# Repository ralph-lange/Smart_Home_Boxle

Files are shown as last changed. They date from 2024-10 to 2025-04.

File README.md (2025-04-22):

# Smart Home Böxle

The Smart Home Böxle is a pretty little wooden box that combines a classic analogue ammeter with an e-Ink display to visualize home automation data. (‘Böxle’ is German, Swabian to be precise, and means ‘little box’.)

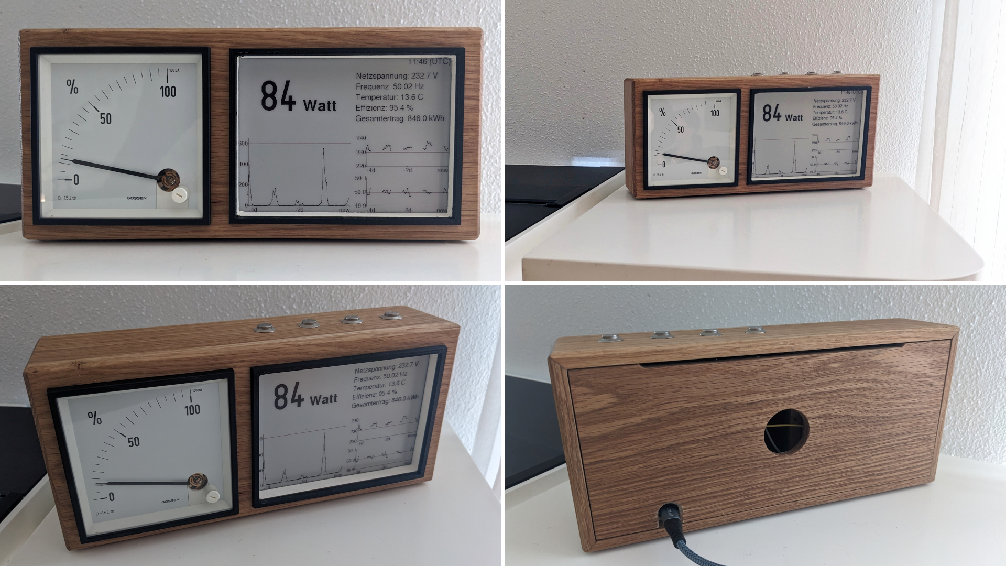
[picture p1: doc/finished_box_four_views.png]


## Parts list

- 8mm solid wood (here oak was used)
- ESP32 Dev Kit C
- 5.83" E-Paper Display Module by Waveshare (648×480&hairsp;px, black/red/white)
- Analog ammeter or voltmeter with size 96x96&hairsp;mm (here a 100&hairsp;µA ammeter by [Gossen](https://g-mw.de/) was used)
- USB-C female socket
- Micro-USB cable
- Pushbutton switches (4 pieces)
- Acrylic glass panel (here a black panel was used)
- White acrylic paint

... and some DuPont cables, PCB spacers, pin strip, heat shrink tube, and similar typical electronic components.

For the black frame around the cutout of the e-paper display, a standard 3D printer was used.

## Build instructions

The box consists of a rectangular body and a front panel. At the back, a removable cover is inserted into the body.

It is best to first cut the cutouts for the ammeter and the e-paper display in the front panel on a router table. Only then saw the front panel to size, with one or two millimeters tolerance on all four sides.

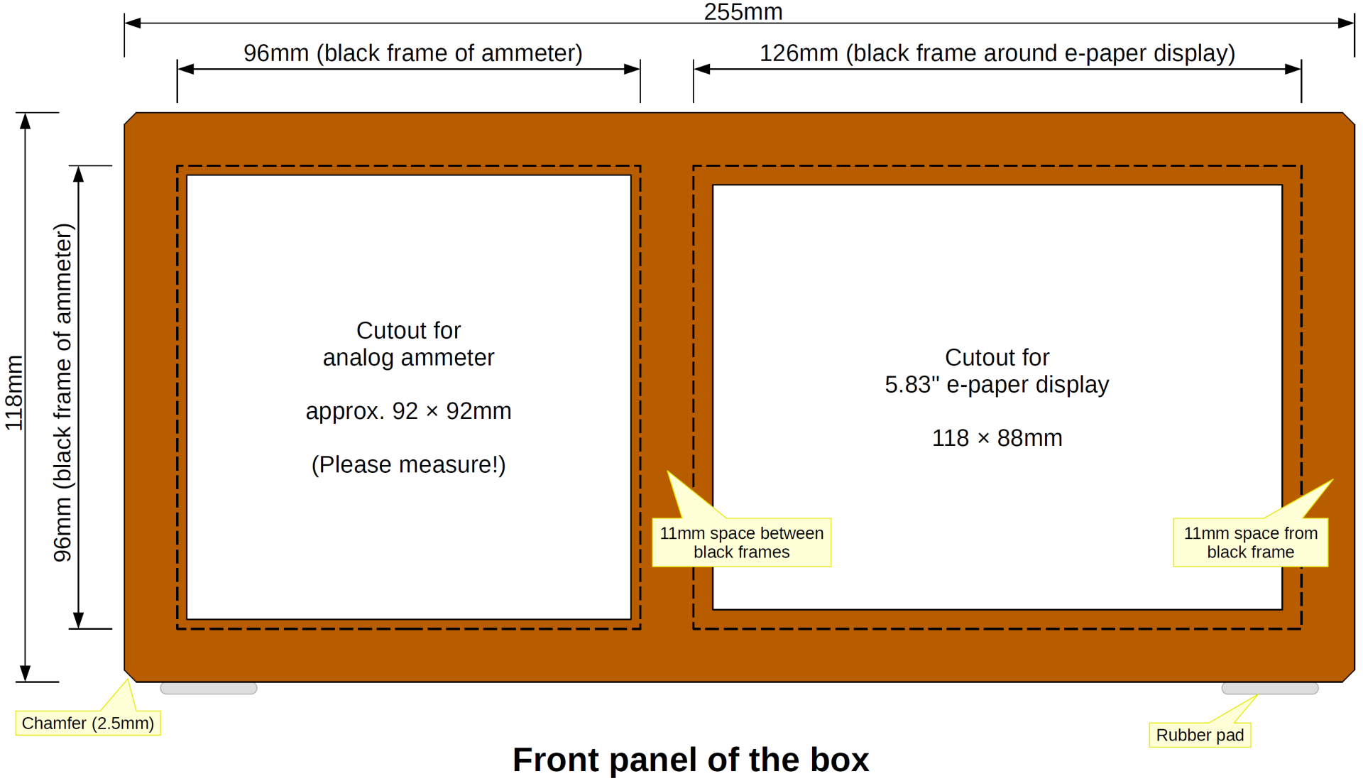
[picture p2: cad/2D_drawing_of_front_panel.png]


The body is built from four wood strips of the same width with 45° miters. The width of the wood strips is determined primarily by the depth of the ammeter. The lengths of the wood strips are 255mm and 118mm, respectively.

But before gluing the wood strips, drill four holes for the pushbutton switches into the top wood strip. Furthermore, remove a small strip on the upper inside front for the e-paper display since the display's top border is wider than the other borders.

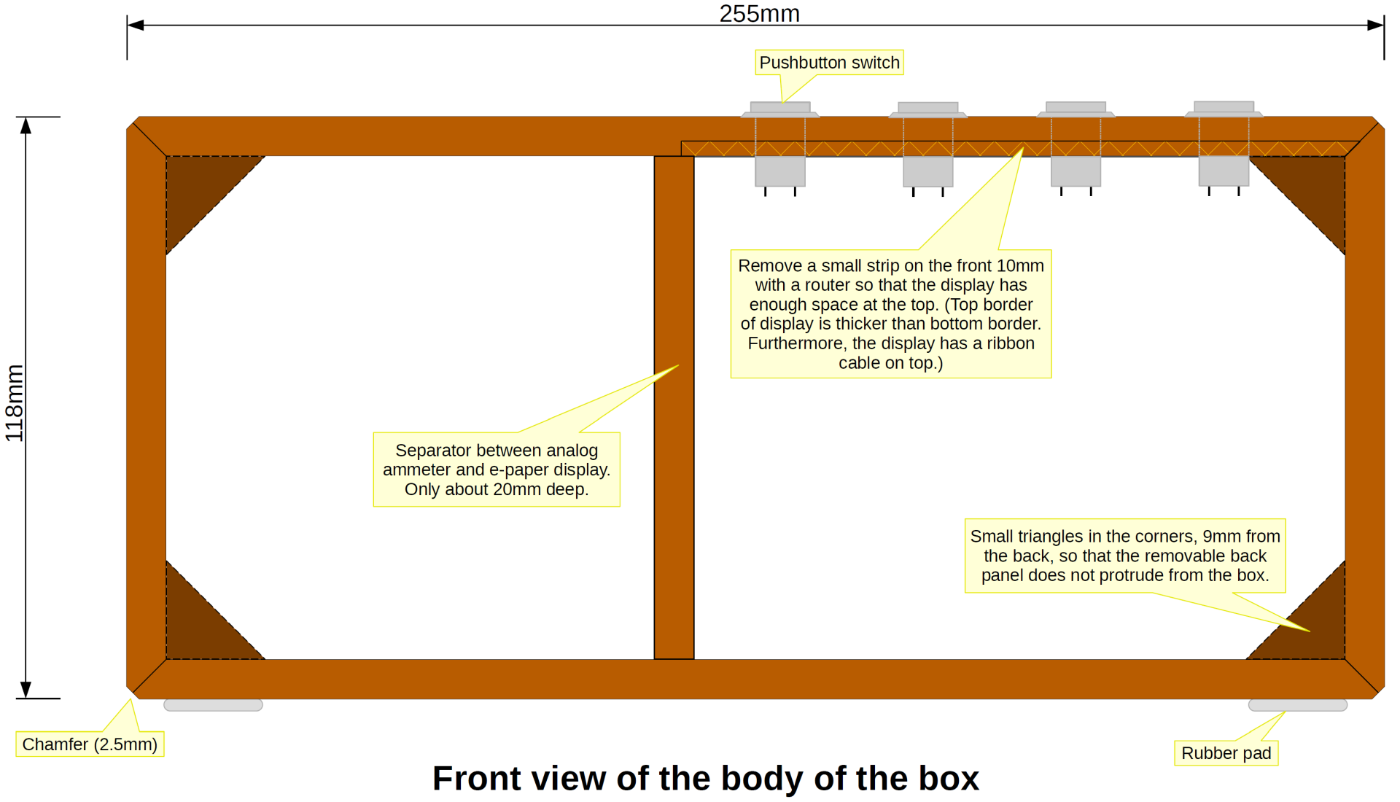
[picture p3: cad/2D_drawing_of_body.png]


Glue small triangles 9mm from the back into the corners of the body. Furthermore, glue a vertical separator between the space for the ammeter and the space for the e-paper display.

Glue the front panel on the body, remove the protruding wood of the front panel using a flush cutter on a router table. Cut a small chamfer all around the box.

Paint the inner sides of the cutout for the e-paper display with a white acrylic paint.

The e-paper display is delivered with a small ribbon cable and a driver board. Cut a (black) acrylic glass panel that is slightly larger than the display but small enough to fit in the right half of the box. Mount the driver board on the acrylic glass panel, guide the ribbon cable over the edge and attach the display to the other side of the acrylic glass panel with adhesive pads. Slide the acrylic glass panel with the display into the box from the back and place it vertically behind the cutout.

In the photo below, the acrylic glass panel is fixed on the left and right by two other acrylic glass panels which were glued with double-sided adhesive tape.

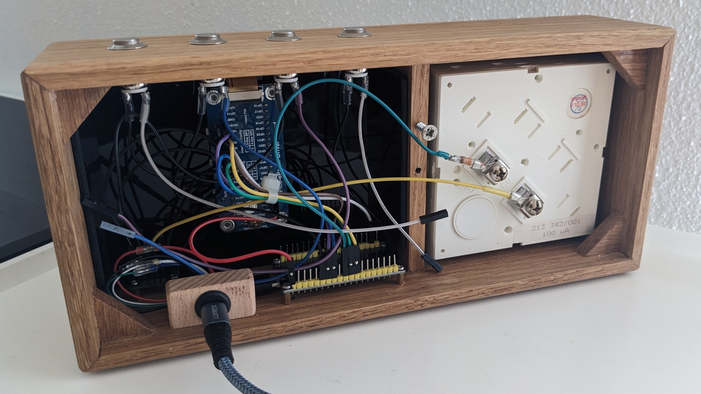
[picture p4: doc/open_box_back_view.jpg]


The wiring of the driver board for SPI is shown below on the left.

After inserting and tightening the four pushbutton switches, mount the ESP32 reversed at the bottom of the frame using PCB spacers. I screwed the spacers through the wood from below. I also drilled a hole from the bottom side to the boot button so that it can be pushed with a thin pen or screwdriver for flashing the ESP32. (Alternatively, you may ground GPIO 0 with a DuPont cable for entering the flashing mode.)

In addition to the ESP32, I mounted a small circuit board with a pin strip for grounding the pushbutton switches, the e-paper display, and the ammeter to the GND pin of the ESP32. The middle image below shows this pin strip.

For power supply and flashing, I cut off a four-wire micro-USB cable and soldered it to a four-contact USB-C socket (see photo below right). The socket is attached using a small wooden block.

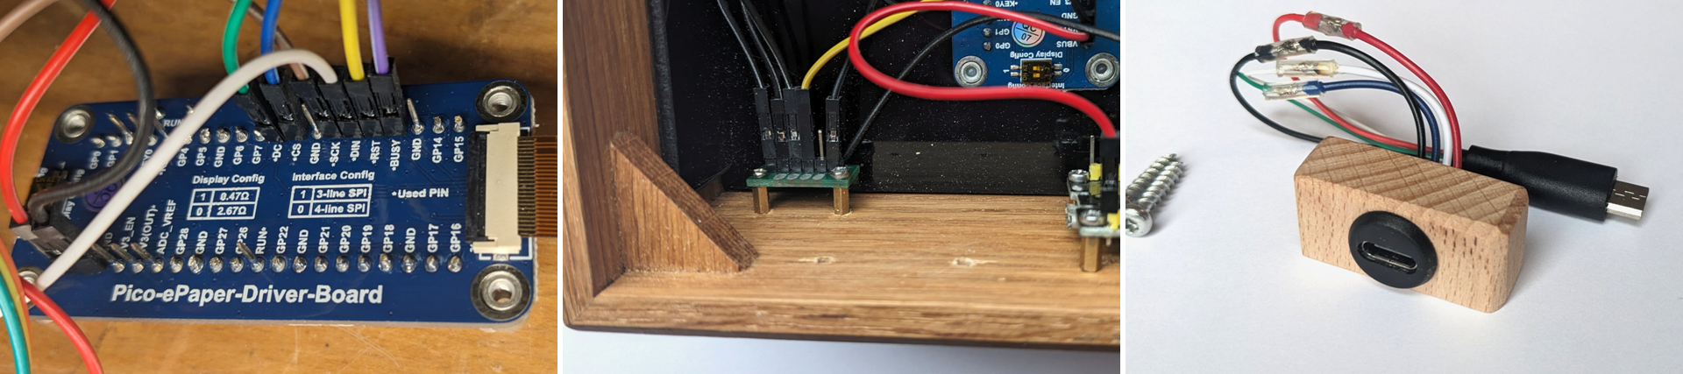
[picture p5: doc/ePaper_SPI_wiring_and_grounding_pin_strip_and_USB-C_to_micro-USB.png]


Mount/glue a small black frame around the cutout of the e-paper display. An STL file for 3D printing such a frame can is stored at [cad/black_frame_for_e-paper_display.stl](cad/black_frame_for_e-paper_display.stl).

Next, insert the ammeter in the box. I fixed it with some foam stuffed around the ammeter.

The last step is the back cover, which is placed in the body. Drill a finger-sized hole in the center so that it can be easily taken out. I used a hand-held router to additionally drill two holes for the contacts of the ammeter, which protrude a little further. Furthermore, I glued in a small magnet to hold the cover magnetically at a screw in the vertical wood strip between the ammeter and the e-paper display. To avoid any interference, ensure that the screw and the magnet are a few centimeters away from the coil of the ammeter.

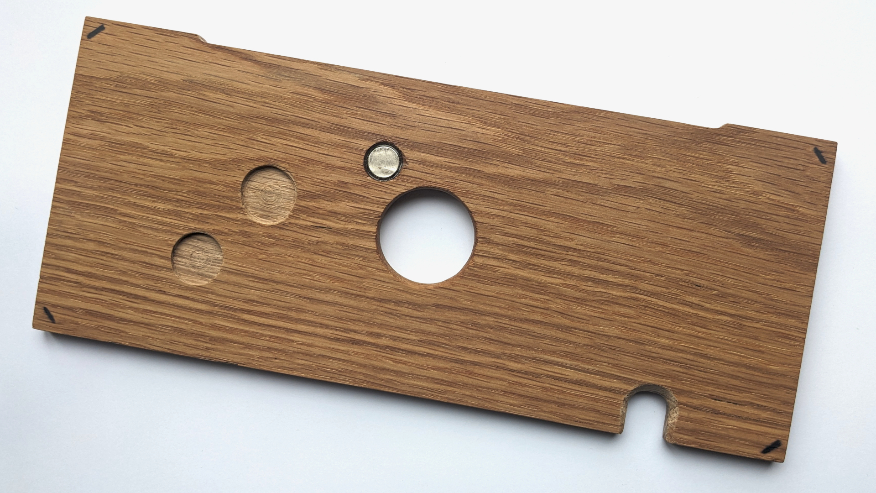
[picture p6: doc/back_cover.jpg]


The above 2D drawings can be found in scale 1:1 in [cad/2D_drawings_of_front_panel_and_body.pdf](cad/2D_drawings_of_front_panel_and_body.pdf).

## Wiring

Wire the e-paper display to the ESP32 as follows:

| E-paper Display | ESP32 Dev Kit C |
| :---: | :---: |
| VSYS+ | 5V |
| GND | GND |
| &ast;DC | GPIO 25 |
| &ast;CS | GPIO 14 |
| &ast;SCK | GPIO 18 |
| &ast;DIN | GPIO 23 |
| &ast;RST | GPIO 33 |
| &ast;BUSY | GPIO 12 |

The plus terminal of the ammeter is connected to GPIO 26.

The four pushbutton switches are each connected to GND and to GPIO 17 respectively 16, 2, or 15.

## Software

The software was implemented using the Arduino IDE and the Arduino-ESP platform. The main software can be found in [src/smart_home_boxle/smart_home_boxle.ino](src/smart_home_boxle/smart_home_boxle.ino). All dependencies are documented directly at the beginning with the include directives.

The file [src/smart_home_boxle/plot_utility.h](src/smart_home_boxle/plot_utility.h) contains a small utility class for 2D plots.

Put your secrets `WIFI_SSID`, `WIFI_PASSWORD`, and `THINGSPEAK_CHANNEL` in a file named screts.h in the same folder. This file is excluded from version control, cf. [.gitignore](.gitignore).

## Tools

The file [tools/analog_out_sinus/analog_out_sinus.ino](tools/analog_out_sinus/analog_out_sinus.ino) provides a small tooling program that outputs a 0.25 Hz sinus between 0 and 3.3 V on GPIO 25. This may be used to test an analog ammeter or voltmeter as depicted below.

<p align="center">
  
</p>

In the video, a 100&hairsp;µA ammeter is used with a 33&hairsp;kΩ at GPIO 25.

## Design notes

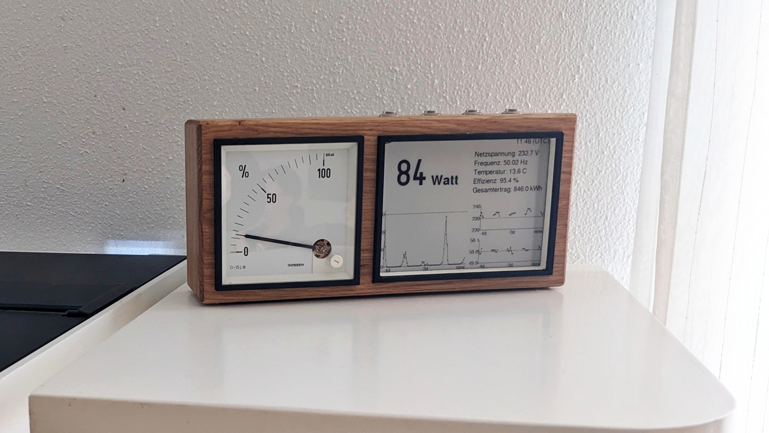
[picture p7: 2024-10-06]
doc/finished_box_wide_view.jpg

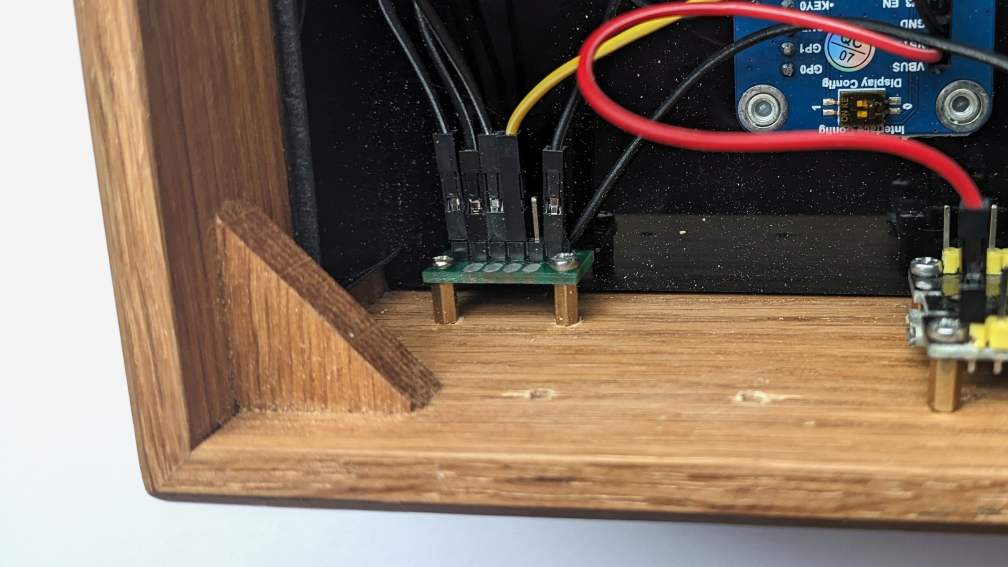
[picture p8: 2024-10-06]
doc/grounding_pin_strip.jpg

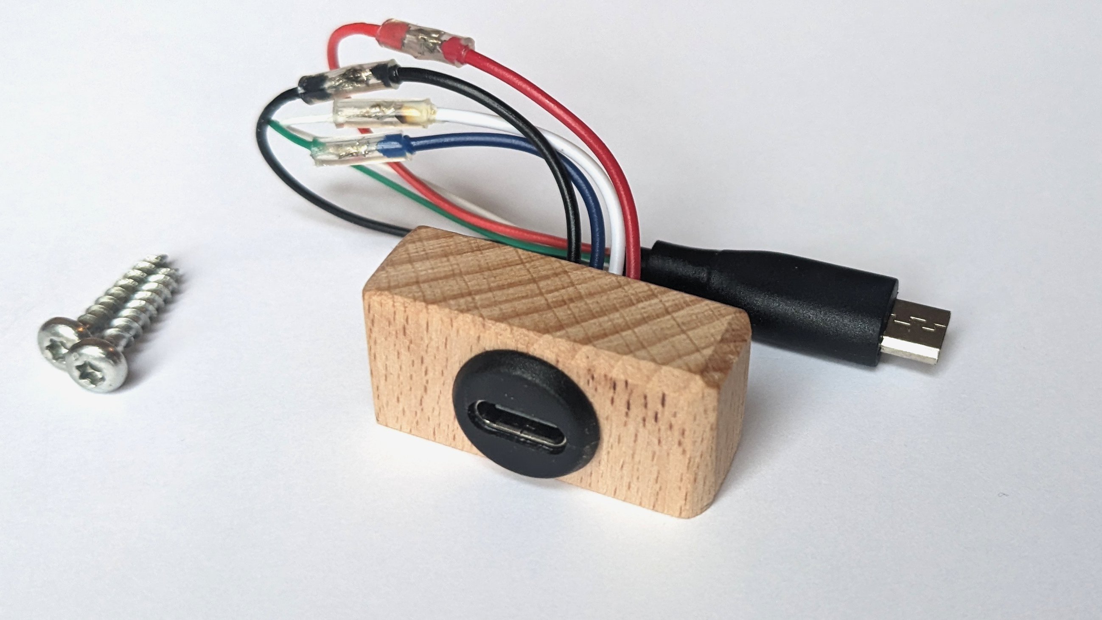
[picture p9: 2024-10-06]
doc/USB-C_to_micro-USB.jpg

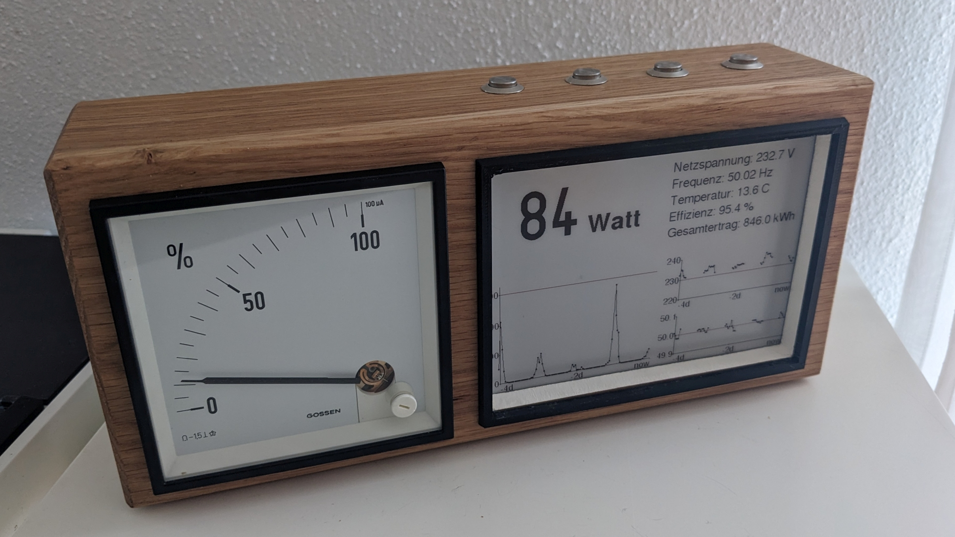
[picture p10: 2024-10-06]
doc/finished_box_angular_view.jpg

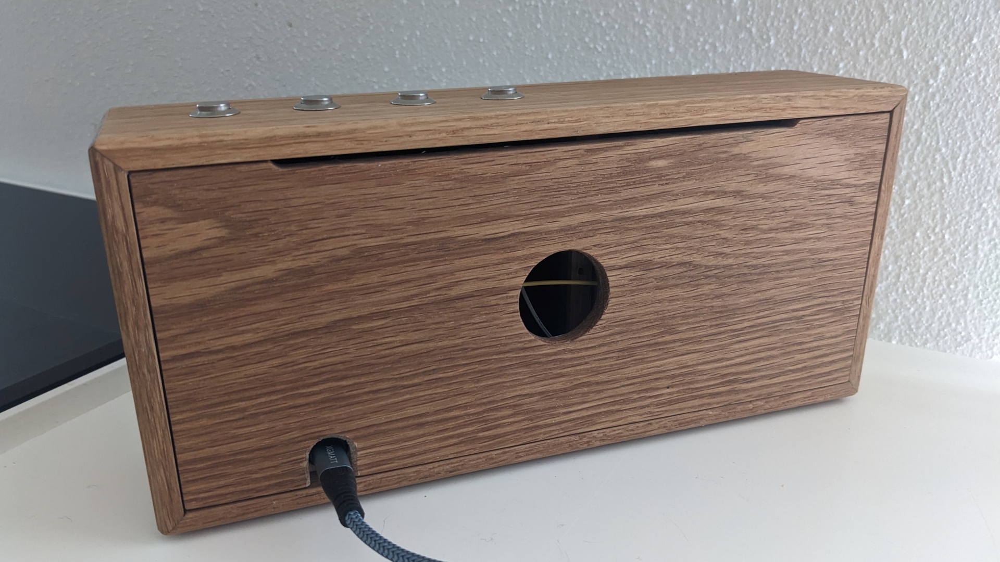
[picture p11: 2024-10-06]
doc/finished_box_back_view.jpg

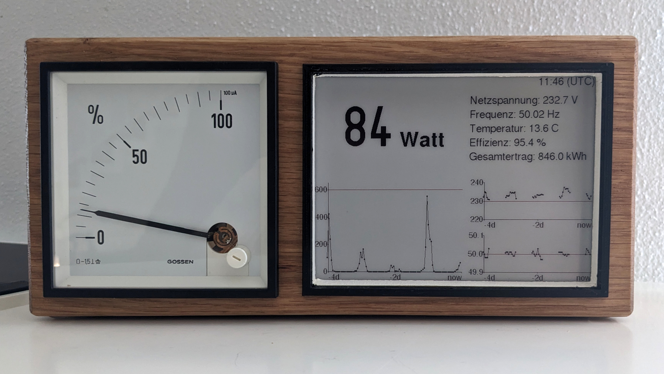
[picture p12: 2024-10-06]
doc/finished_box_front_view.jpg

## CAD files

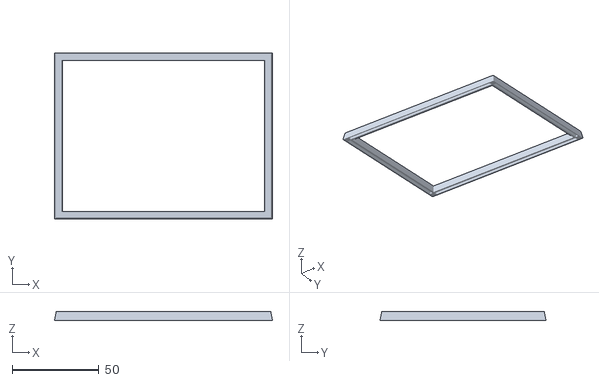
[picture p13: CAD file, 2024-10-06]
cad/black_frame_for_e-paper_display.stl
126.0 x 96.0 x 5.00

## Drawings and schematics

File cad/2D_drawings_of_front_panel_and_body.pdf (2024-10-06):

## 126mm (black frame around e-paper display)

255mm

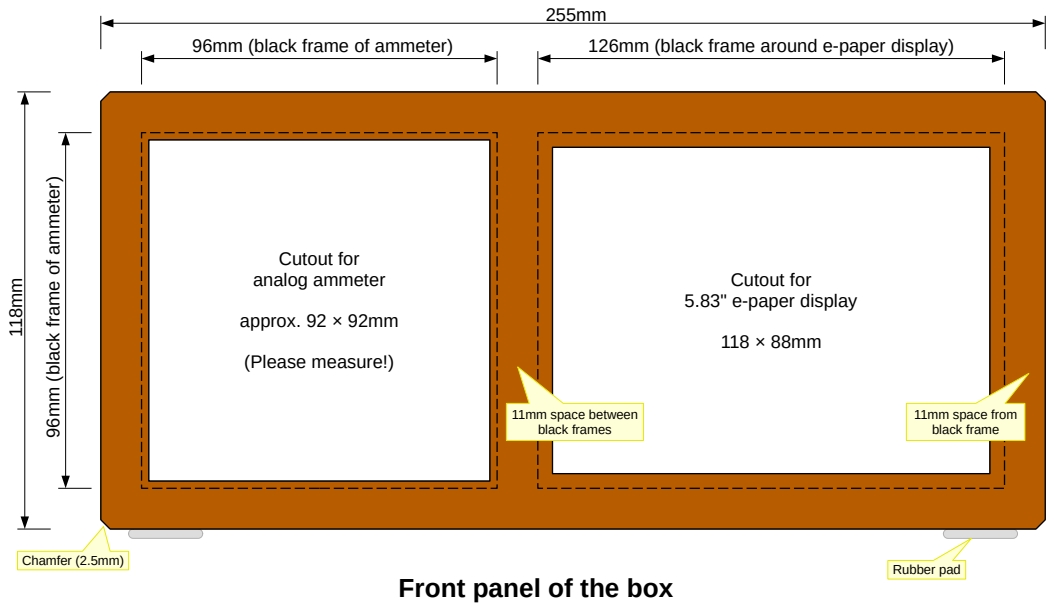
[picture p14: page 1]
m (bla; k fra; eter); Rubber pad; Cutout for analog ammeter; approx. 92 × 92mm; (Please measure!); Cutout for 5.83" e-paper display; Chamfer (2.5mm); 11mm space from black frame; 11mm space between black frames

96mm (black frame of ammeter)

Front panel of the box

255mm

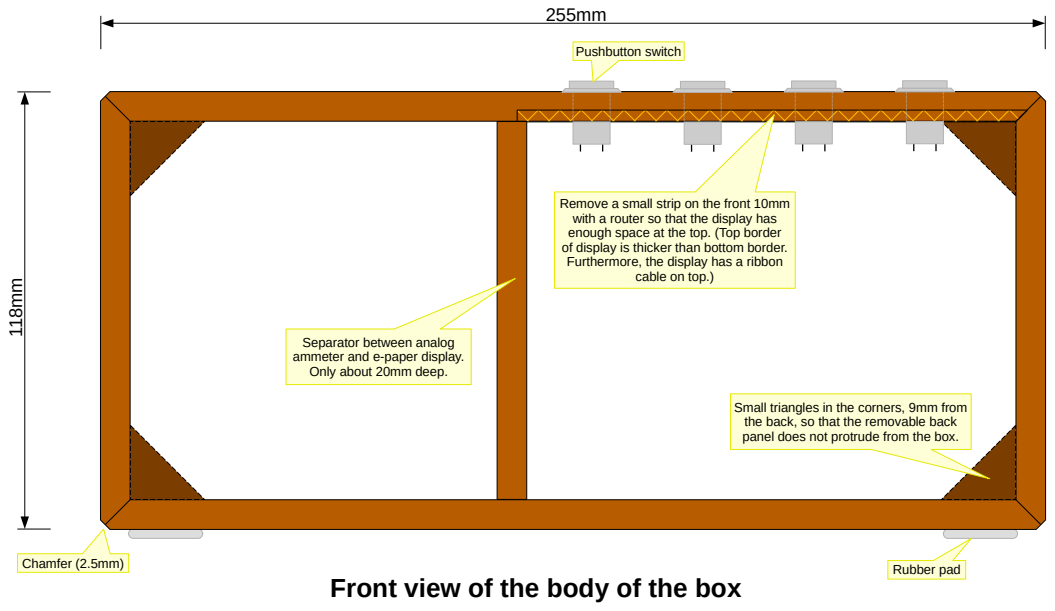
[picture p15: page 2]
Rubber pad; Pushbutton switch; Chamfer (2.5mm)

Remove a small strip on the front 10mm
with a router so that the display has
enough space at the top. (Top border
of display is thicker than bottom border.
Furthermore, the display has a ribbon

cable on top.)

Separator between analog
ammeter and e-paper display.
Only about 20mm deep.

Small triangles in the corners, 9mm from
the back, so that the removable back
panel does not protrude from the box.

Front view of the body of the box

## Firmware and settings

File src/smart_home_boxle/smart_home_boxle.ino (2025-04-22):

// Copyright (c) 2024-2025 Ralph Lange
// All rights reserved.
//
// This source code is licensed under the BSD 3-Clause license found in the
// LICENSE file in the root directory of this source tree.


// TODOs:
// - Restore zoom function, connect it with push buttons, and preserve zoom between reboots.
// - Implement calibration function using the four push buttons.


#include <cstdint>

#include <vector>

#include <WiFi.h>  // Platform 'esp32' by Espressif (here V2.0.11)
#include <time.h>
#include <HTTPClient.h>

#include <ArduinoJson.h>  // Library 'ArduinoJson' by Benoit Blanchon (here V7.2.0)

#include <GxEPD2_3C.h>  // Library 'GxEPD2' by Jean-Marc Zingg (here V1.6.0).

#include <U8g2_for_Adafruit_GFX.h>  // Library 'U8g2_for_Adafruit_GFX' by oliver (here V1.8.0)
#include <Fonts/FreeSans9pt7b.h>
#include <Fonts/FreeSans12pt7b.h>
#include <Fonts/FreeSansBold24pt7b.h>

#include "plot_utility.h"
#include "secrets.h"  // Define WIFI_SSID, WIFI_PASSWORD, and THINGSPEAK_CHANNEL in this file.


TaskHandle_t longRunningFunctionsTask;

const int AMMETER_PIN = 26;

const int PUSH_BUTTON_A_PIN = 17;
const int PUSH_BUTTON_B_PIN = 16;
const int PUSH_BUTTON_C_PIN = 2;
const int PUSH_BUTTON_D_PIN = 15;

const int E_PAPER_CS = 14;
const int E_PAPER_DC = 25;
const int E_PAPER_RST = 33;
const int E_PAPER_BUSY = 12;

GxEPD2_3C<GxEPD2_583c_Z83, GxEPD2_583c_Z83::HEIGHT>* displayPtr;

#define NTP_SERVER "de.pool.ntp.org"

const int MAX_ZOOM = 6;
const std::array<int, MAX_ZOOM + 1> ZOOM_TO_RESOLUTION_MINUTES{ 10,   20,       30,       60,       60,       240,       720};
const std::array<int, MAX_ZOOM + 1> ZOOM_TO_RANGE_MINUTES{     720, 1440, 2 * 2440, 4 * 1440, 8 * 1440, 16 * 1440, 32 * 1440};


U8G2_FOR_ADAFRUIT_GFX u8g2Fonts;

SemaphoreHandle_t globalMutex = NULL;
int zoom = 3;
bool isNtpInitialized = false;


#define HAS_STEPPER_AS_AMMETER false
#if HAS_STEPPER_AS_AMMETER
  #include <ESP32Servo.h>  // Library 'ESP32Servo' V3.0.6 by Kevin Harrington, John K. Bennett.
  Servo ammeterServo;
#endif


/// Struct for a single data item from the photovoltaic system. 
struct PVSingleData {
  double age = 0.0;
  float pAC = 0.0f;
  float uAC = 0.0f;
  float frequency = 0.0f;
  float temperature = 0.0f;
  float efficiency = 0.0f;
  float totalYield = 0.0f;  
};

PVSingleData newestData; 


/// Waits up to the given number of milliseconds for the WiFi to connect.
void waitUntilWiFiConnectedOrTimeout(long timeout_ms) {
  assert(timeout_ms >= 5000);

  const int WAIT_STEP_TIME_MS = 100;
  long maxSteps = timeout_ms / WAIT_STEP_TIME_MS;
  for (long step = 0; step < maxSteps && WiFi.status() != WL_CONNECTED; ++step) {
    delay(WAIT_STEP_TIME_MS);
  }  
}


/// Tries to connect to WiFi the given number of times.
bool tryConnectWiFi(size_t attemps) {
  size_t index = 0;
  Serial.print(F("Connecting to WiFi ."));
  while(WiFi.status() != WL_CONNECTED && index < attemps) {
    index++;
    WiFi.begin(WIFI_SSID, WIFI_PASSWORD);
    Serial.print(".");
    waitUntilWiFiConnectedOrTimeout(5000);
  } 
  Serial.println("");
  
  if (WiFi.status() != WL_CONNECTED) {
    Serial.println(F("Could not connect to WiFi."));
    return false;
  }

  Serial.println(F("Connected to WiFi successfully."));
  return true;
}


/// Sends the given HTTP request and returns the response - or an empty
/// string if the request failed.
String tryHTTPRequest(const String& url, size_t attempts) {
  Serial.print(F("Sending HTTP request to "));
  Serial.print(url);
  Serial.println(".");
  
  int response = -1;
  String content = "";
  size_t index = 0;
  do {
    index++;
    HTTPClient http;
    http.begin(url.c_str());
    response = http.GET();
    content = http.getString();
    http.end();
  } while(response != 200 && index < attempts);
  
  if (response != 200) {
    Serial.print(F("Problem with REST query: HTTP error code is "));
    Serial.println(response);
    return String("");
  }
  
  Serial.println(F("REST query successful."));
  return content;
}


/// Queries the newest/latest data from the ThingSpeak channel. The argument
/// currentTime is used to determine the relative age of the data.
void queryNewestData(tm& currentTime) {
  String url = "https://api.thingspeak.com/channels/" + String(THINGSPEAK_CHANNEL) + "/feeds.json?results=1";
  String content = tryHTTPRequest(url, 5);
  DynamicJsonDocument doc(10 * 1024);
  DeserializationError errorMsg = deserializeJson(doc, content.c_str());
  if (errorMsg) {
    Serial.print(F("JSON deserialization failed: "));
    Serial.println(errorMsg.f_str());
    return;
  }
  if (doc["feeds"].size() == 0) {
    Serial.println(F("Feed is empty!"));
    return;
  }

  tm timestamp;
  strptime(doc["feeds"][0]["created_at"], "%Y-%m-%dT%H:%M:%SZ", &timestamp);

  xSemaphoreTake(globalMutex, 10 * portTICK_PERIOD_MS);
  newestData.age = static_cast<double>(difftime(mktime(&currentTime), mktime(&timestamp)));
  newestData.pAC = doc["feeds"][0]["field3"];
  newestData.uAC = doc["feeds"][0]["field1"];
  newestData.frequency = doc["feeds"][0]["field2"];
  newestData.temperature = doc["feeds"][0]["field4"];
  newestData.efficiency = doc["feeds"][0]["field5"];
  newestData.totalYield = doc["feeds"][0]["field6"];
  xSemaphoreGive(globalMutex); 
}


/// Queries a timeseries/curve for the given field from the ThingSpeak channel.
/// The currentTime is used to determine the relative age of each data point.
/// The argument zoom determines the temporal resolution.
std::vector<PlotPoint> queryCurveGeneric(tm& currentTime, int zoom, int field) {
  String fieldAsString(field);
  String url = "https://api.thingspeak.com/channels/" + String(THINGSPEAK_CHANNEL) + "/fields/" + fieldAsString + ".json?median=" + String(ZOOM_TO_RESOLUTION_MINUTES[zoom]) + "&minutes=" + String(ZOOM_TO_RANGE_MINUTES[zoom]);
  String content = tryHTTPRequest(url, 5);
  DynamicJsonDocument doc(50 * 1024);
  DeserializationError errorMsg = deserializeJson(doc, content.c_str());
  if (errorMsg) {
    Serial.print(F("JSON deserialization failed: "));
    Serial.println(errorMsg.f_str());
    return std::vector<PlotPoint>();
  }
  
  std::vector<PlotPoint> result;
  result.reserve(200);
  for (size_t index = 0; index < doc["feeds"].size(); ++index) {
    double pac = doc["feeds"][index]["field" + fieldAsString];
    tm timestamp;
    strptime(doc["feeds"][index]["created_at"], "%Y-%m-%dT%H:%M:%SZ", &timestamp);
    double relativeTime = static_cast<double>(difftime(mktime(&timestamp), mktime(&currentTime)));
    result.push_back({relativeTime, pac});
  }
  
  return result;
}


/// Queries the P_AC timeseries/curve from the ThingSpeak channel. The
/// currentTime is used to determine the relative age of each data point.
/// The argument zoom determines the temporal resolution.
std::vector<PlotPoint> queryPACCurve(tm& currentTime, int zoom) {
  return queryCurveGeneric(currentTime, zoom, 3);
}


/// Queries the frequency timeseries/curve from the ThingSpeak channel. The
/// currentTime is used to determine the relative age of each data point.
/// The argument zoom determines the temporal resolution.
std::vector<PlotPoint> queryFrequencyCurve(tm& currentTime, int zoom) {
  return queryCurveGeneric(currentTime, zoom, 2);
}


/// Queries the U_AC timeseries/curve from the ThingSpeak channel. The
/// currentTime is used to determine the relative age of each data point.
/// The argument zoom determines the temporal resolution.
std::vector<PlotPoint> queryUACCurve(tm& currentTime, int zoom) {
  return queryCurveGeneric(currentTime, zoom, 1);
}


/// The main function (static schedule) for all long-running functions
/// such as querying ThingSpeak and updating the e-Ink display.
void longRunningFunctionsMain(void*) {
  WiFiClient client;
  WiFi.mode(WIFI_STA);

  long nextPlotRedrawMillis = 0;

  while(millis() < 3600 * 1000) {
    if (WiFi.status() != WL_CONNECTED) {
      tryConnectWiFi(5);      
    } else if (!isNtpInitialized) {
      Serial.println(F("Initializing NTP ..."));
      configTime(0, 0, NTP_SERVER);
      struct tm currentTime;
      if (getLocalTime(&currentTime, 10000)){
        Serial.println(F("Queried NTP server successfully."));
        isNtpInitialized = true;
      } else {
        Serial.println(F("Could not initialize NTP!"));
      }
    } else if (millis() > nextPlotRedrawMillis) {
      queryDataAndRedraw(zoom);
      nextPlotRedrawMillis = millis() + 180 * 1000;  // Normally do not redraw faster than 3 minutes.
    }
    delay(10);
  }

  ESP.restart();
}


/// The main function (static schedule) for all short-running functions
/// such as determining the state of the push buttons and updating the
/// analogy display.
void shortRunningFunctionsMain() {
  unsigned long nextRegularAmmeterUpdateMillis = millis();
  int lastAnalogDisplayValue = -1;
  while(true) {
    int analogDisplayValue = 0;

    if (digitalRead(PUSH_BUTTON_A_PIN) == LOW) {
      Serial.println("Push button A (very left) is pressed.");
    }
    if (digitalRead(PUSH_BUTTON_B_PIN) == LOW) {
      Serial.println("Push button B (middle left) is pressed.");
    }
    if (digitalRead(PUSH_BUTTON_C_PIN) == LOW) {
      Serial.println("Push button C (middle right) is pressed.");
    }
    if (digitalRead(PUSH_BUTTON_D_PIN) == LOW) {
      Serial.println("Push button D (very right) is pressed.");
    }

    if (digitalRead(PUSH_BUTTON_A_PIN) == LOW) {
      // Sinus wave with 0.25 Hz.
      analogDisplayValue = 128 + static_cast<int>(127.0f * sin(0.25 * 2.0f * PI * millis() / 1000.0f));
    } else if (digitalRead(PUSH_BUTTON_B_PIN) == LOW) {
      // Show zero power value.
      float pAC = 0.0f;
      analogDisplayValue = static_cast<int>(255.0f * pAC / 1000.0f);
    } else if (digitalRead(PUSH_BUTTON_C_PIN) == LOW) {
      // Show power value of 300 W.
      float pAC = 300.0f;
      analogDisplayValue = static_cast<int>(255.0f * pAC / 1000.0f);
    } else if (digitalRead(PUSH_BUTTON_D_PIN) == LOW) {
      // Show power value of 600 W.
      float pAC = 600.0f;
      analogDisplayValue = static_cast<int>(255.0f * pAC / 1000.0f);
    } else {
      xSemaphoreTake(globalMutex, 10 * portTICK_PERIOD_MS);
      if (newestData.totalYield > 0 && newestData.age < 900) {
        analogDisplayValue = static_cast<int>(255.0f * newestData.pAC / 1000.0f);
      }
      xSemaphoreGive(globalMutex);
    }
    analogDisplayValue = std::min(analogDisplayValue, 255);
    analogDisplayValue = std::max(analogDisplayValue, 0);

    if (analogDisplayValue != lastAnalogDisplayValue || millis() >= nextRegularAmmeterUpdateMillis) {
#ifdef STEPPER_AS_AMMETER
      ammeterServo.attach(AMMETER_PIN);
      int angle = static_cast<int>(90.0f * analogDisplayValue / 255.0f);
      ammeterServo.write(angle);
      delay(200);
      ammeterServo.detach();
#else
      analogWrite(AMMETER_PIN, analogDisplayValue);
#endif
      // Avoid continuous update of ammeter, which may cause strange sounds
      // if ammeter is implemented by stepper motor.
      nextRegularAmmeterUpdateMillis = millis() + 5000;
      lastAnalogDisplayValue = analogDisplayValue;
    }
    delay(100);
  }
}


/// The start-up function called by the ESP32 platform.
void setup() {
  Serial.begin(115200);

  displayPtr = new GxEPD2_3C<GxEPD2_583c_Z83, GxEPD2_583c_Z83::HEIGHT>(GxEPD2_583c_Z83(E_PAPER_CS, E_PAPER_DC, E_PAPER_RST, E_PAPER_BUSY));

  pinMode(AMMETER_PIN, OUTPUT);

  pinMode(PUSH_BUTTON_A_PIN, INPUT_PULLUP);
  pinMode(PUSH_BUTTON_B_PIN, INPUT_PULLUP);
  pinMode(PUSH_BUTTON_C_PIN, INPUT_PULLUP);
  pinMode(PUSH_BUTTON_D_PIN, INPUT_PULLUP);

  Serial.print("Initializing display ...");
  displayPtr->init();
  u8g2Fonts.begin(*displayPtr);
  Serial.println(" done.");

  globalMutex = xSemaphoreCreateMutex();
}


/// The main function called by the ESP32 platform. It is splitted into two
/// threads for long-running and short-running functions.
void loop() {
  xTaskCreatePinnedToCore(longRunningFunctionsMain, "longRunningFunctionsTask", 25000, NULL, 0, &longRunningFunctionsTask, 0);
  shortRunningFunctionsMain();
}


/// Converts the given relative time (negative number of seconds) into a
/// string representation in hours or even days for the x-axes of the plots. 
String relativeHoursOrDayLabelFromSeconds(int seconds) {
  assert(seconds <= 0);

  if (seconds == 0) {
    return String("now");
  } else if (seconds == -3 * 3600) {
    return String("-3h");
  } else if (seconds == -6 * 3600) {
    return String("-6h");
  } else if (seconds == -12 * 3600) {
    return String("-12h");
  } else if (seconds <= -24 * 3600) {
    return "-" + String(seconds / (-24 * 3600)) + "d";
  }

  assert(false);  
  return String("?");
}


/// Queries all data from the ThingSpeak channel and updates the whole
/// e-Ink display accordingly.
void queryDataAndRedraw(int zoom) {
  struct tm currentTime;
  if (!getLocalTime(&currentTime, 10000)) {
    Serial.println(F("Could not get current time!"));
    return;
  }

  // secondsDiffModuloOneMinute = currentTime.tm_sec - (millis() / 1000);
  queryNewestData(currentTime);
  std::vector<PlotPoint> pacCurve = queryPACCurve(currentTime, zoom);
  std::vector<PlotPoint> uacCurve = queryUACCurve(currentTime, zoom);
  std::vector<PlotPoint> frequencyCurve = queryFrequencyCurve(currentTime, zoom);
    
  displayPtr->setFullWindow();
  displayPtr->setRotation(2);
  displayPtr->setTextColor(GxEPD_BLACK);
  u8g2Fonts.setForegroundColor(GxEPD_BLACK);
  u8g2Fonts.setBackgroundColor(GxEPD_WHITE);
  displayPtr->firstPage();

  PlotUtility pacPlot(40, 235, 360 - 15 - 40, 208, - ZOOM_TO_RANGE_MINUTES[zoom] * 60, 0, 0, 650);
  pacPlot.setXTicks({{- ZOOM_TO_RANGE_MINUTES[zoom] * 60, relativeHoursOrDayLabelFromSeconds(- ZOOM_TO_RANGE_MINUTES[zoom] * 60)},
                  {- ZOOM_TO_RANGE_MINUTES[zoom] * 30, relativeHoursOrDayLabelFromSeconds(- ZOOM_TO_RANGE_MINUTES[zoom] * 30)},
                  {0, relativeHoursOrDayLabelFromSeconds(0)}});
  pacPlot.setYTicks({{0, "0"}, {200, "200"}, {400, "400"}, {600, "600"}});
  
  PlotUtility uacPlot(360 + 35, 235, 635 - (360 + 35), 86, - ZOOM_TO_RANGE_MINUTES[zoom] * 60, 0, 220, 240);
  uacPlot.setXTicks({{- ZOOM_TO_RANGE_MINUTES[zoom] * 60, relativeHoursOrDayLabelFromSeconds(- ZOOM_TO_RANGE_MINUTES[zoom] * 60)},
                  {- ZOOM_TO_RANGE_MINUTES[zoom] * 30, relativeHoursOrDayLabelFromSeconds(- ZOOM_TO_RANGE_MINUTES[zoom] * 30)},
                  {0, relativeHoursOrDayLabelFromSeconds(0)}});
  uacPlot.setYTicks({{220, "220"}, {230, "230"}, {240, "240"}});
  
  PlotUtility frequencyPlot(360 + 35, 235 + 208 - 86, 635 - (360 + 35), 86, - ZOOM_TO_RANGE_MINUTES[zoom] * 60, 0, 49.9, 50.1);
  frequencyPlot.setXTicks({{- ZOOM_TO_RANGE_MINUTES[zoom] * 60, relativeHoursOrDayLabelFromSeconds(- ZOOM_TO_RANGE_MINUTES[zoom] * 60)},
                  {- ZOOM_TO_RANGE_MINUTES[zoom] * 30, relativeHoursOrDayLabelFromSeconds(- ZOOM_TO_RANGE_MINUTES[zoom] * 30)},
                  {0, relativeHoursOrDayLabelFromSeconds(0)}});
  frequencyPlot.setYTicks({{49.9, "49.9"}, {50.0, "50.0"}, {50.1, "50.1"}});
  
  Serial.println(F("Starting redrawing of e-paper display."));
  do {
    displayPtr->fillScreen(GxEPD_WHITE);

    // Current P_AC.
    if (newestData.totalYield > 0 && newestData.age < 900) {
      u8g2Fonts.setFont(u8g2_font_logisoso92_tn);
      String currentPAC = String(newestData.pAC, 0);
      int16_t textWidth = u8g2Fonts.getUTF8Width(currentPAC.c_str());
      u8g2Fonts.setCursor(200 - 20 - textWidth, 156);
      u8g2Fonts.print(currentPAC);
      displayPtr->setFont(&FreeSansBold24pt7b);
      displayPtr->setCursor(200, 156);
      displayPtr->print("Watt");
    } else {
      displayPtr->setFont(&FreeSansBold24pt7b);
      displayPtr->setCursor(0, 156);
      displayPtr->print("Kein Ertrag!");
    }

    // Current time.
    displayPtr->setFont(&FreeSans12pt7b);
    char stringBuffer[50];
    strftime(stringBuffer, sizeof(stringBuffer), "%H:%M", &currentTime);
    String timeString = stringBuffer + String(" (UTC)");
    displayPtr->setCursor(635 - display_getTextWidth(timeString), 21);
    displayPtr->print(timeString);

    // Other current values
    displayPtr->setFont(&FreeSans12pt7b);
    String currentUAC = "Netzspannung: -";
    String currentFrequency = "Frequenz: -";
    String currentTemperature = "Temperatur: -";
    String currentEfficiency = "Effizienz: -";
    String totalYield = "Gesamtertrag: -";
    if (newestData.totalYield > 0) {
      if (newestData.age < 900) {
        currentUAC = "Netzspannung: " + String(newestData.uAC, 1) + " V";
        currentFrequency = "Frequenz: " + String(newestData.frequency, 2) + " Hz";
        currentTemperature = "Temperatur: " + String(newestData.temperature, 1) + " C";
        currentEfficiency = "Effizienz: " + String(newestData.efficiency, 1) + " %";
      }
      totalYield = "Gesamtertrag: " + String(newestData.totalYield, 1) + " kWh";
    }
    displayPtr->setCursor(360, 60);
    displayPtr->print(currentUAC);
    displayPtr->setCursor(360, 92);
    displayPtr->print(currentFrequency);
    displayPtr->setCursor(360, 124);
    displayPtr->print(currentTemperature);
    displayPtr->setCursor(360, 156);
    displayPtr->print(currentEfficiency);
    displayPtr->setCursor(360, 188);
    displayPtr->print(totalYield);

    {
      int y = pacPlot.getYPixelForYValue(600.0);
      displayPtr->drawLine(40, y, 360 - 15, y, GxEPD_RED);
    }

    pacPlot.drawXAxis([displayPtr](int x0, int y0, int x1, int y1) {
      displayPtr->drawLine(x0, y0, x1, y1, GxEPD_BLACK);
    });

    pacPlot.drawYAxis([displayPtr](int x0, int y0, int x1, int y1) {
      displayPtr->drawLine(x0, y0, x1, y1, GxEPD_BLACK);
    });

    pacPlot.drawXTicks([displayPtr](int x, int y, double relativePosition, String label) {
      displayPtr->drawLine(x, y, x, y + 2, GxEPD_BLACK);
      displayPtr->setFont(&FreeSans9pt7b);
      displayPtr->setCursor(x - static_cast<int>(relativePosition * display_getTextWidth(label)), y + 18);
      displayPtr->print(label.c_str());
    });

    pacPlot.drawYTicks([displayPtr](int x, int y, double relativePosition, String label) {
      displayPtr->drawLine(x - 2, y, x, y, GxEPD_BLACK);
      displayPtr->setFont(&FreeSans9pt7b);
      displayPtr->setCursor(40 - 4 - display_getTextWidth(label), y + 5);
      displayPtr->print(label.c_str());
    });

    pacPlot.drawPoints(pacCurve, [displayPtr](int x, int y, PlotPoint point) {
      displayPtr->fillRect(x - 1, y - 1, 3, 3, GxEPD_BLACK);
    });

    pacPlot.drawLinesBetweenPoints(pacCurve, [displayPtr](int x0, int y0, int x1, int y1, PlotPoint point0, PlotPoint point1) {
      displayPtr->drawLine(x0, y0, x1, y1, GxEPD_BLACK);
    });

    {
      int y = uacPlot.getYPixelForYValue(230.0);
      displayPtr->drawLine(360 + 35, y, 635, y, GxEPD_RED);
    }

    uacPlot.drawXAxis([displayPtr](int x0, int y0, int x1, int y1) {
      displayPtr->drawLine(x0, y0, x1, y1, GxEPD_BLACK);
    });

    uacPlot.drawYAxis([displayPtr](int x0, int y0, int x1, int y1) {
      displayPtr->drawLine(x0, y0, x1, y1, GxEPD_BLACK);
    });

    uacPlot.drawXTicks([displayPtr](int x, int y, double relativePosition, String label) {
      displayPtr->drawLine(x, y, x, y + 2, GxEPD_BLACK);
      displayPtr->setFont(&FreeSans9pt7b);
      displayPtr->setCursor(x - static_cast<int>(relativePosition * display_getTextWidth(label)), y + 18);
      displayPtr->print(label.c_str());
    });

    uacPlot.drawYTicks([displayPtr](int x, int y, double relativePosition, String label) {
      displayPtr->drawLine(x - 2, y, x, y, GxEPD_BLACK);
      displayPtr->setFont(&FreeSans9pt7b);
      displayPtr->setCursor(360 + 35 - 4 - display_getTextWidth(label), y + 5);
      displayPtr->print(label.c_str());
    });

    uacPlot.drawPoints(uacCurve, [displayPtr](int x, int y, PlotPoint point) {
      if (point.y != 0.0) {
        displayPtr->fillRect(x - 1, y - 1, 3, 3, GxEPD_BLACK);
      }
    });

    uacPlot.drawLinesBetweenPoints(uacCurve, [displayPtr](int x0, int y0, int x1, int y1, PlotPoint point0, PlotPoint point1) {
      if (point0.y != 0.0 && point1.y != 0.0) {
        displayPtr->drawLine(x0, y0, x1, y1, GxEPD_BLACK);
      }
    });

    {
      int y = frequencyPlot.getYPixelForYValue(50.0);
      displayPtr->drawLine(360 + 35, y, 635, y, GxEPD_RED);      
    }

    frequencyPlot.drawXAxis([displayPtr](int x0, int y0, int x1, int y1) {
      displayPtr->drawLine(x0, y0, x1, y1, GxEPD_BLACK);
    });

    frequencyPlot.drawYAxis([displayPtr](int x0, int y0, int x1, int y1) {
      displayPtr->drawLine(x0, y0, x1, y1, GxEPD_BLACK);
    });

    frequencyPlot.drawXTicks([displayPtr](int x, int y, double relativePosition, String label) {
      displayPtr->drawLine(x, y, x, y + 2, GxEPD_BLACK);
      displayPtr->setFont(&FreeSans9pt7b);
      displayPtr->setCursor(x - static_cast<int>(relativePosition * display_getTextWidth(label)), y + 18);
      displayPtr->print(label.c_str());
    });

    frequencyPlot.drawYTicks([displayPtr](int x, int y, double relativePosition, String label) {
      displayPtr->drawLine(x - 2, y, x, y, GxEPD_BLACK);
      displayPtr->setFont(&FreeSans9pt7b);
      displayPtr->setCursor(360 + 35 - 4 - display_getTextWidth(label), y + 5);
      displayPtr->print(label.c_str());
    });

    frequencyPlot.drawPoints(frequencyCurve, [displayPtr](int x, int y, PlotPoint point) {
      if (point.y != 0.0) {
        displayPtr->fillRect(x - 1, y - 1, 3, 3, GxEPD_BLACK);
      }
    });

    frequencyPlot.drawLinesBetweenPoints(frequencyCurve, [displayPtr](int x0, int y0, int x1, int y1, PlotPoint point0, PlotPoint point1) {
      if (point0.y != 0.0 && point1.y != 0.0) {
        displayPtr->drawLine(x0, y0, x1, y1, GxEPD_BLACK);
      }
    });
  } while (displayPtr->nextPage());
  Serial.println(F("Redrawing of e-paper display completed."));
  
  Serial.print(F("Powering off the display ..."));
  displayPtr->powerOff();
  Serial.println(F(" done."));
}
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

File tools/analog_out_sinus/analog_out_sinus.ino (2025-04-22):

// Copyright (c) 2024-2025 Ralph Lange
// All rights reserved.
//
// This source code is licensed under the BSD 3-Clause license found in the
// LICENSE file in the root directory of this source tree.


const int AMMETER_PIN = 25;
const float SINUS_FREQUENCY = 0.25f;


void setup() {
  Serial.begin(115200);
  pinMode(AMMETER_PIN, OUTPUT);
}


void loop() {
  float uptimeInSeconds = millis() / 1000.0f;
  int i = 128 + static_cast<int>(127.0f * sin(SINUS_FREQUENCY * 2.0f * PI * uptimeInSeconds));
  Serial.println(i);
  analogWrite(AMMETER_PIN, i);  // i=0 to 255 gives output range from 0.0 to 3.3 V
  delay(25);
}

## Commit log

2024-10-06 Initial commit.
    [black_frame_for_e-paper_display.stl]
2025-02-23 Changed servo library (for support of Arduino-ESP32 V3.x).
2025-02-25 Fixed typo in log messages on serial.
    [smart_home_boxle.ino]
2025-04-22 Added section on wiring to README.md.
